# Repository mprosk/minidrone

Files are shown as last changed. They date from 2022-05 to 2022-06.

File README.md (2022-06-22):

# Minidrone

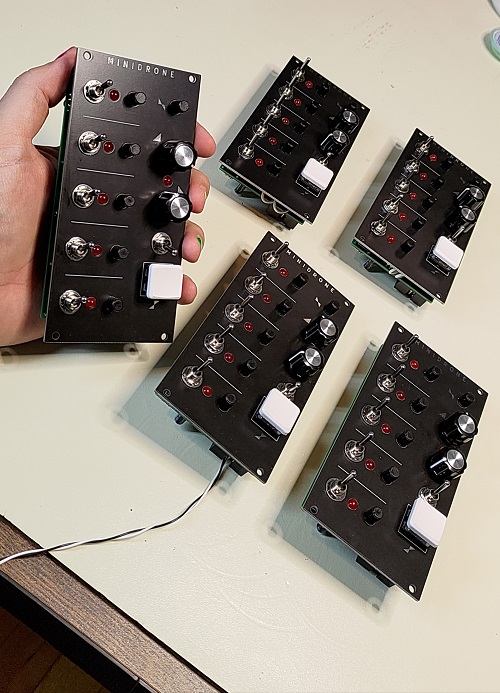
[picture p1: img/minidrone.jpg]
Minidrone


Minidrone is a drone module with a built in Attack/Release amp envelope. It contains five sawtooth oscillators each with individual pitch control and an enable switch. A master pitch control can adjust the tuning of all voices at once. 

Loosely inspired on the Elta Music Solar50

## Case

- 1/2" x 3.5" sheet
  - 2 @ 6.25"
  - 2 @ 13.8"
- 1/4" x 2.5" sheet
  - 2 @ 13.8"
- 1/2" ply
  - 1 @ 13.8" x 5.25"

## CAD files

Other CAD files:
case/minidrone_case.skp

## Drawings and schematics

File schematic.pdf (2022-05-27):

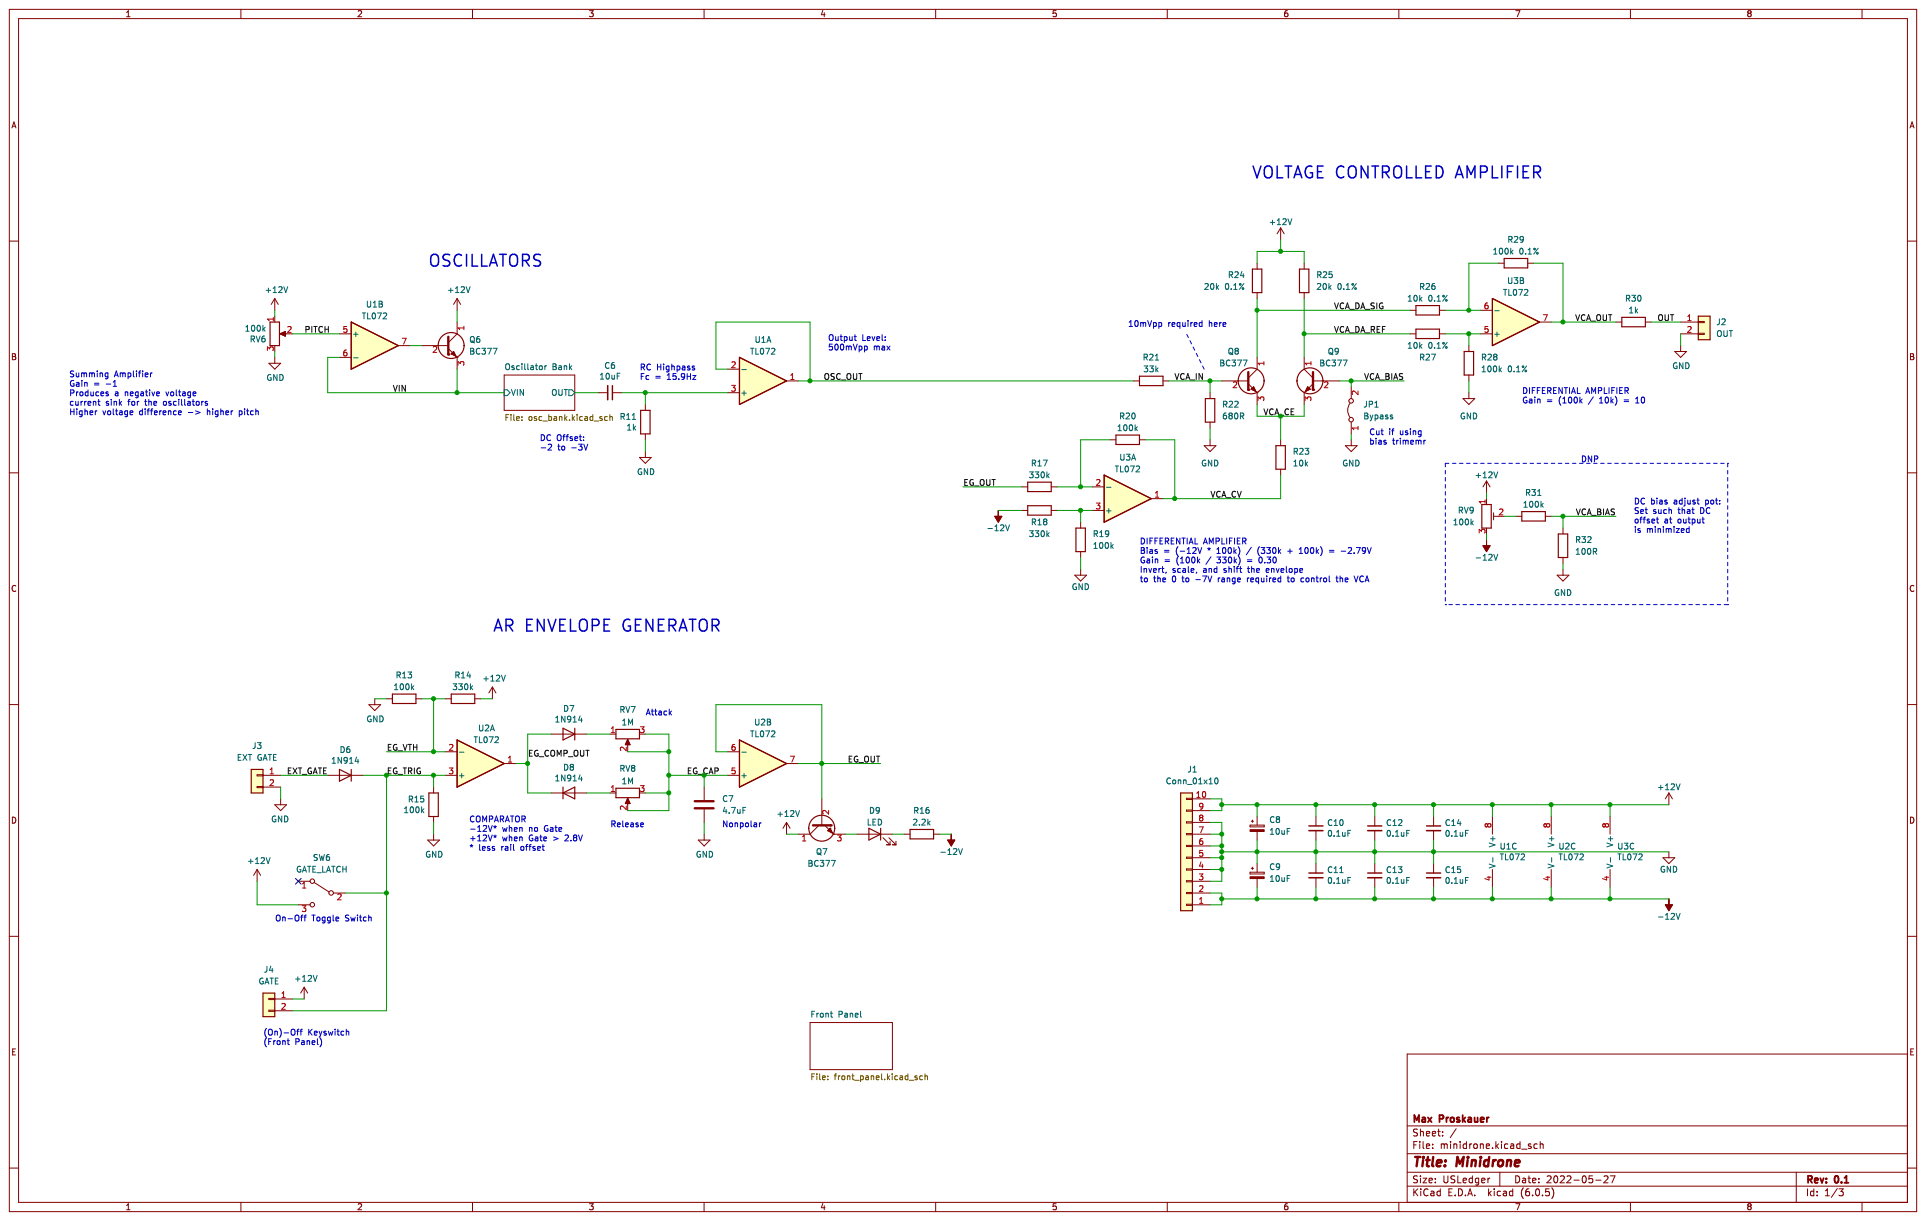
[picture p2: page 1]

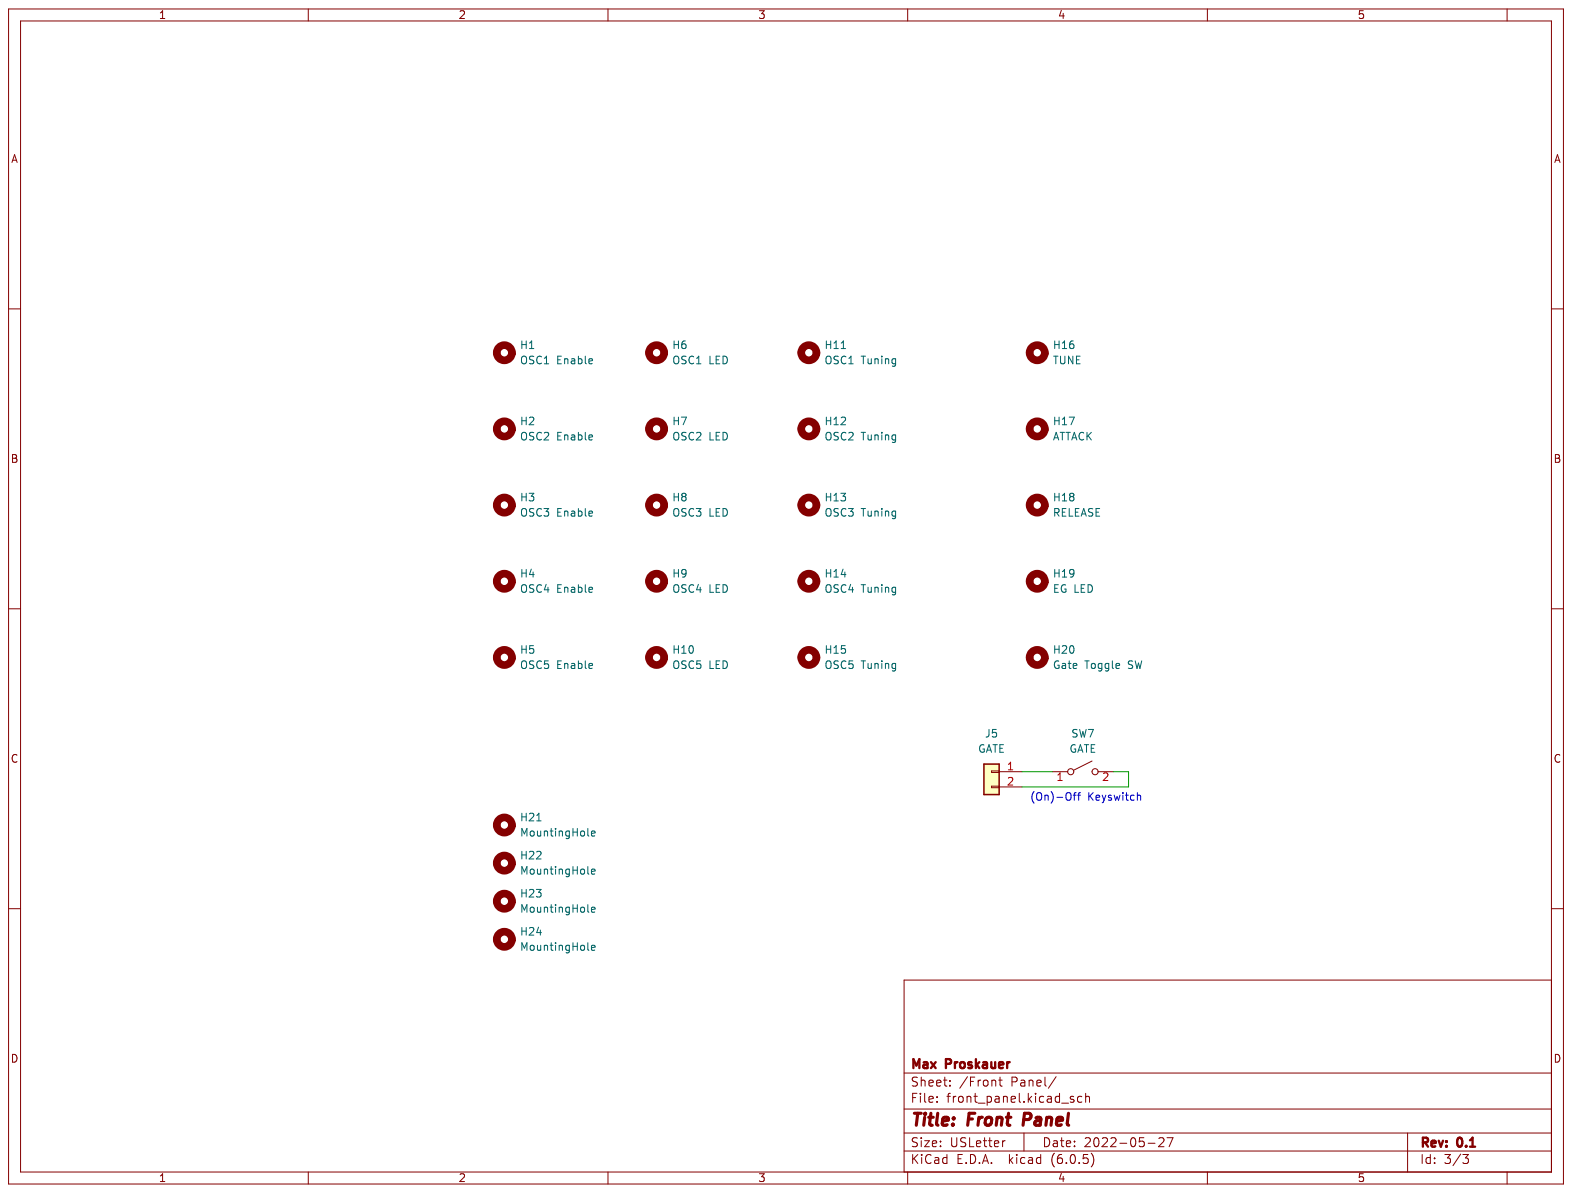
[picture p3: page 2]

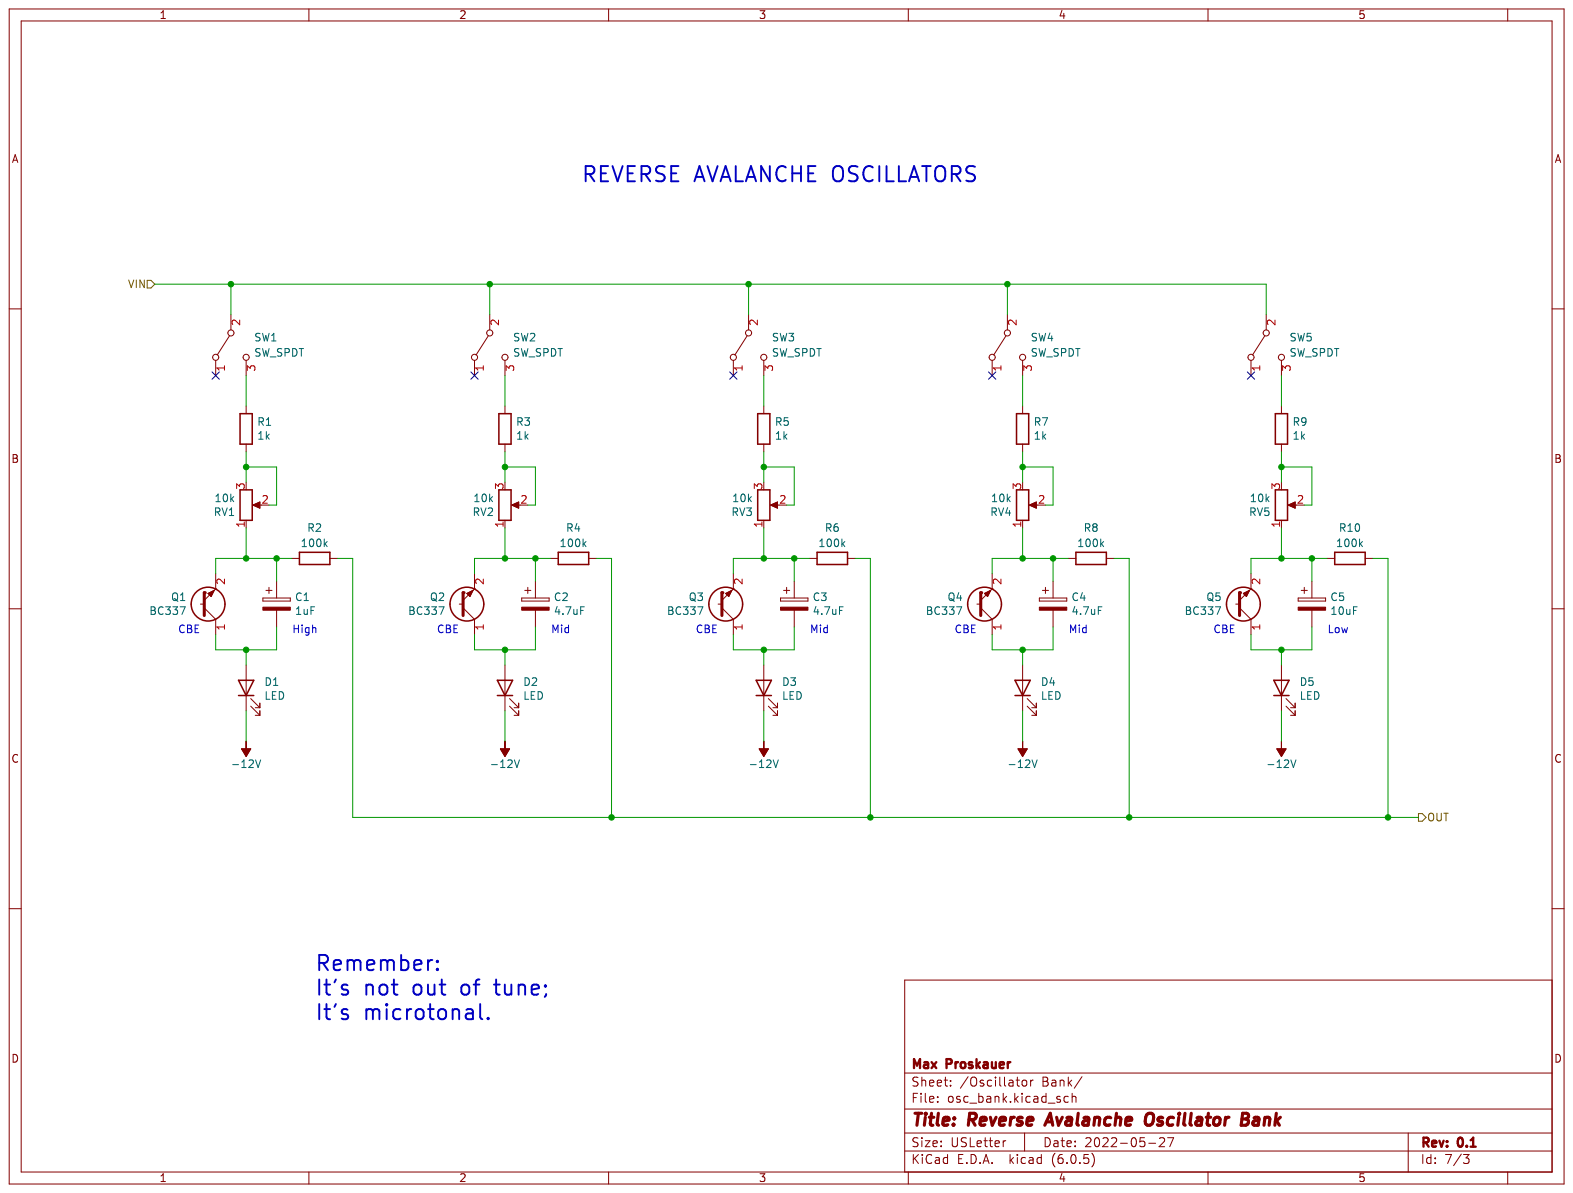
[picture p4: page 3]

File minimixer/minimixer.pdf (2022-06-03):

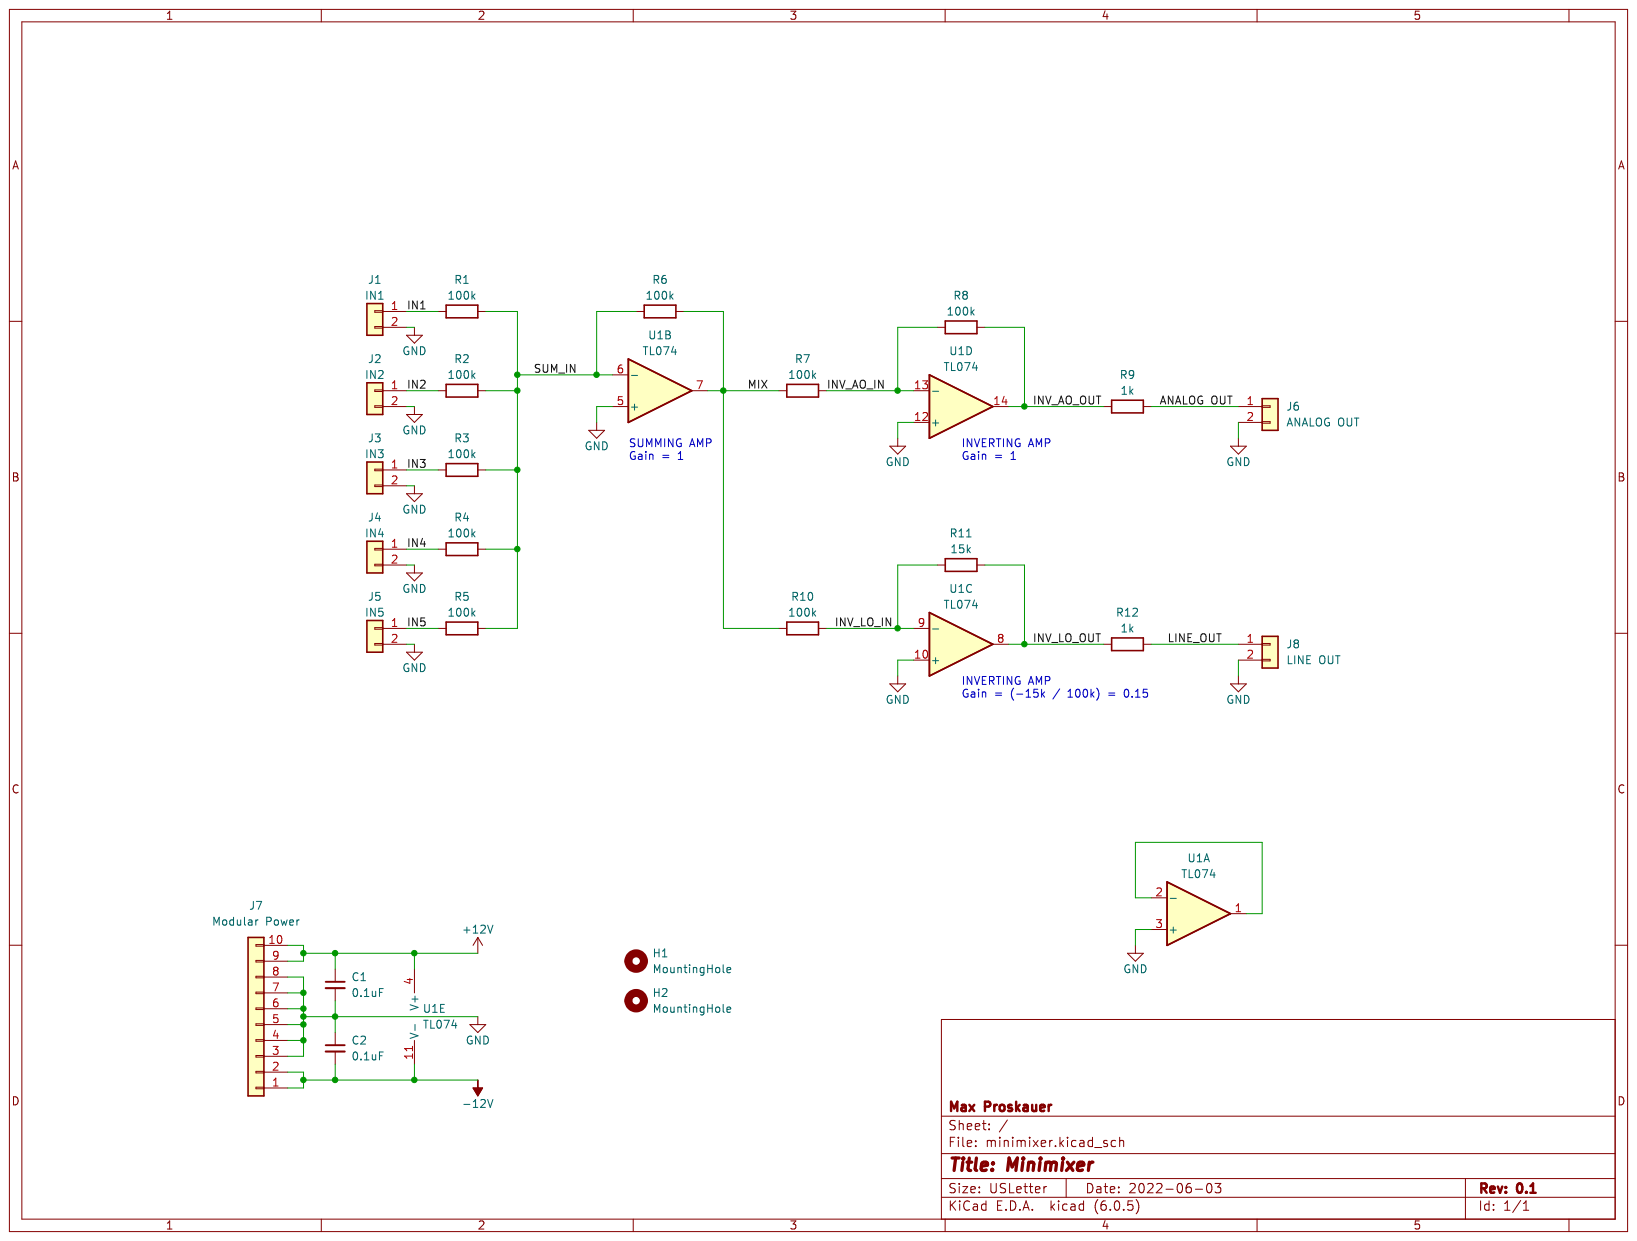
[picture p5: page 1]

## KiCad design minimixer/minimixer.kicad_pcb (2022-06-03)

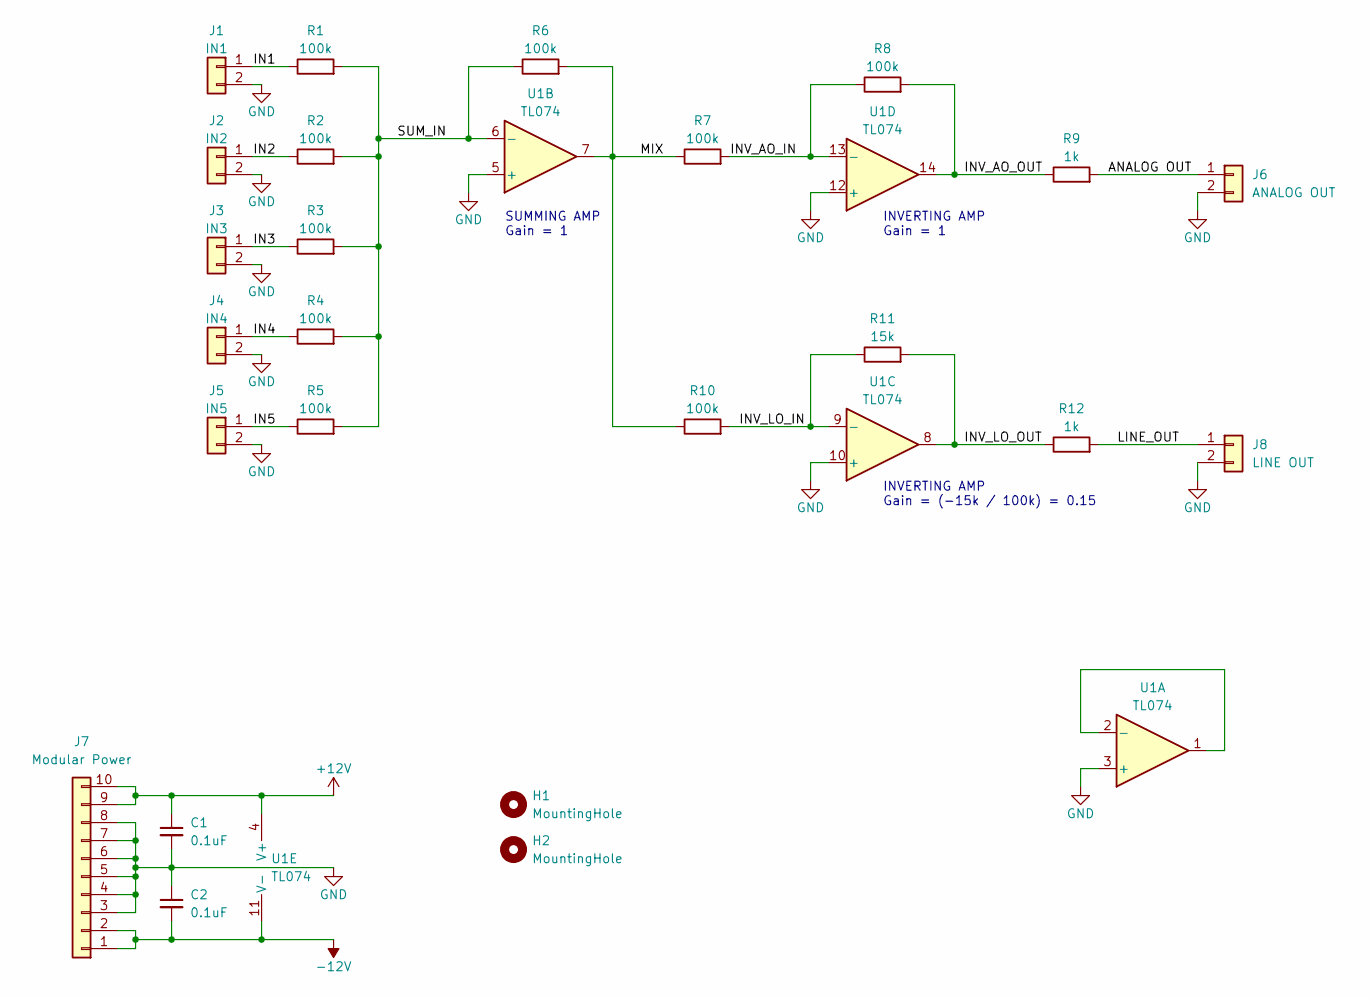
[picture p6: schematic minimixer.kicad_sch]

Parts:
C1, C2: 0.1uF; C_Disc_D3.0mm_W1.6mm_P2.50mm
H1, H2: MountingHole; MountingHole_3.2mm_M3
J1: IN1; Molex_KK-254_AE-6410-02A_1x02_P2.54mm_Vertical
J2: IN2; Molex_KK-254_AE-6410-02A_1x02_P2.54mm_Vertical
J3: IN3; Molex_KK-254_AE-6410-02A_1x02_P2.54mm_Vertical
J4: IN4; Molex_KK-254_AE-6410-02A_1x02_P2.54mm_Vertical
J5: IN5; Molex_KK-254_AE-6410-02A_1x02_P2.54mm_Vertical
J6: ANALOG OUT; Molex_KK-254_AE-6410-02A_1x02_P2.54mm_Vertical
J7: Modular Power; IDC-Header_2x05_P2.54mm_Vertical
J8: LINE OUT; Molex_KK-254_AE-6410-02A_1x02_P2.54mm_Vertical
R1, R2, R3, R4, R5, R6, R7, R10: 100k; R_Axial_DIN0207_L6.3mm_D2.5mm_P10.16mm_Horizontal
R8: 100k; R_Axial_DIN0207_L6.3mm_D2.5mm_P2.54mm_Vertical
R9, R12: 1k; R_Axial_DIN0207_L6.3mm_D2.5mm_P2.54mm_Vertical
R11: 15k; R_Axial_DIN0207_L6.3mm_D2.5mm_P2.54mm_Vertical
U1: TL074; DIP-14_W10.16mm

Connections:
+12V: C1.1, J7.9, J7.10, U1.4 (V+)
-12V: C2.2, J7.1, J7.2, U1.11 (V-)
/ANALOG OUT: J6.1, R9.2
/IN1: J1.1, R1.1
/IN2: J2.1, R2.1
/IN3: J3.1, R3.1
/IN4: J4.1, R4.1
/IN5: J5.1, R5.1
/INV_AO_IN: R7.2, R8.1, U1.13 (-)
/INV_AO_OUT: R8.2, R9.1, U1.14
/INV_LO_IN: R10.2, R11.1, U1.9 (-)
/INV_LO_OUT: R11.2, R12.1, U1.8
/LINE_OUT: J8.1, R12.2
/MIX: R6.2, R7.1, R10.1, U1.7
/SUM_IN: R1.2, R2.2, R3.2, R4.2, R5.2, R6.1, U1.6 (-)
GND: C1.2, C2.1, J1.2, J2.2, J3.2, J4.2, J5.2, J6.2, J7.3, J7.4, J7.5, J7.6, J7.7, J7.8, J8.2, U1.3 (+), U1.5 (+), U1.10 (+), U1.12 (+)
unnamed: U1.1, U1.2 (-)

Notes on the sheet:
INVERTING AMP Gain = (-15k / 100k) = 0.15
SUMMING AMP Gain = 1
INVERTING AMP Gain = 1

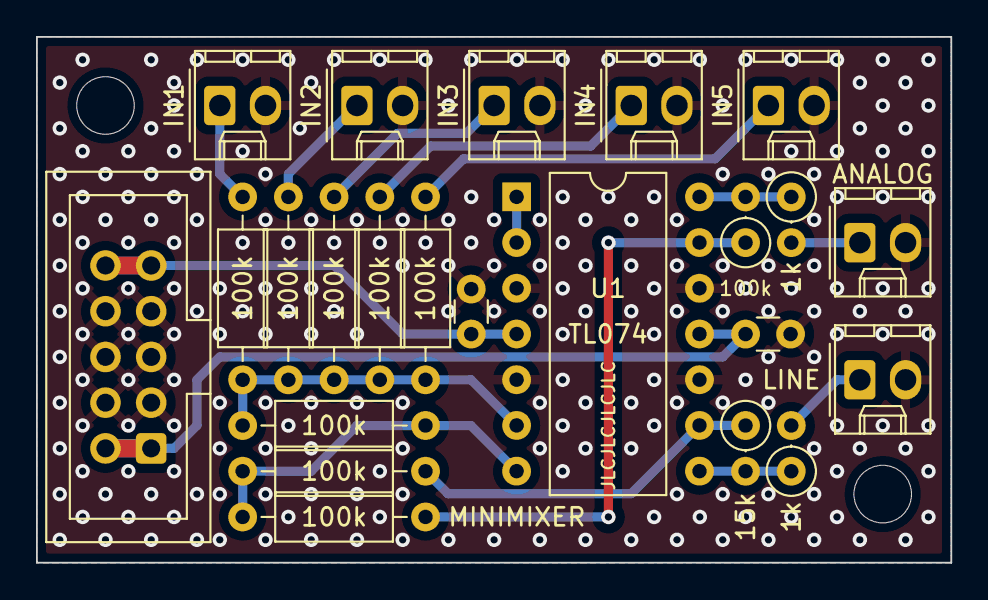
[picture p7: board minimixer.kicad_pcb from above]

Board: 2 copper layers, 50.8 x 29.2 mm, 25 parts (0 on the bottom side), 17 nets.

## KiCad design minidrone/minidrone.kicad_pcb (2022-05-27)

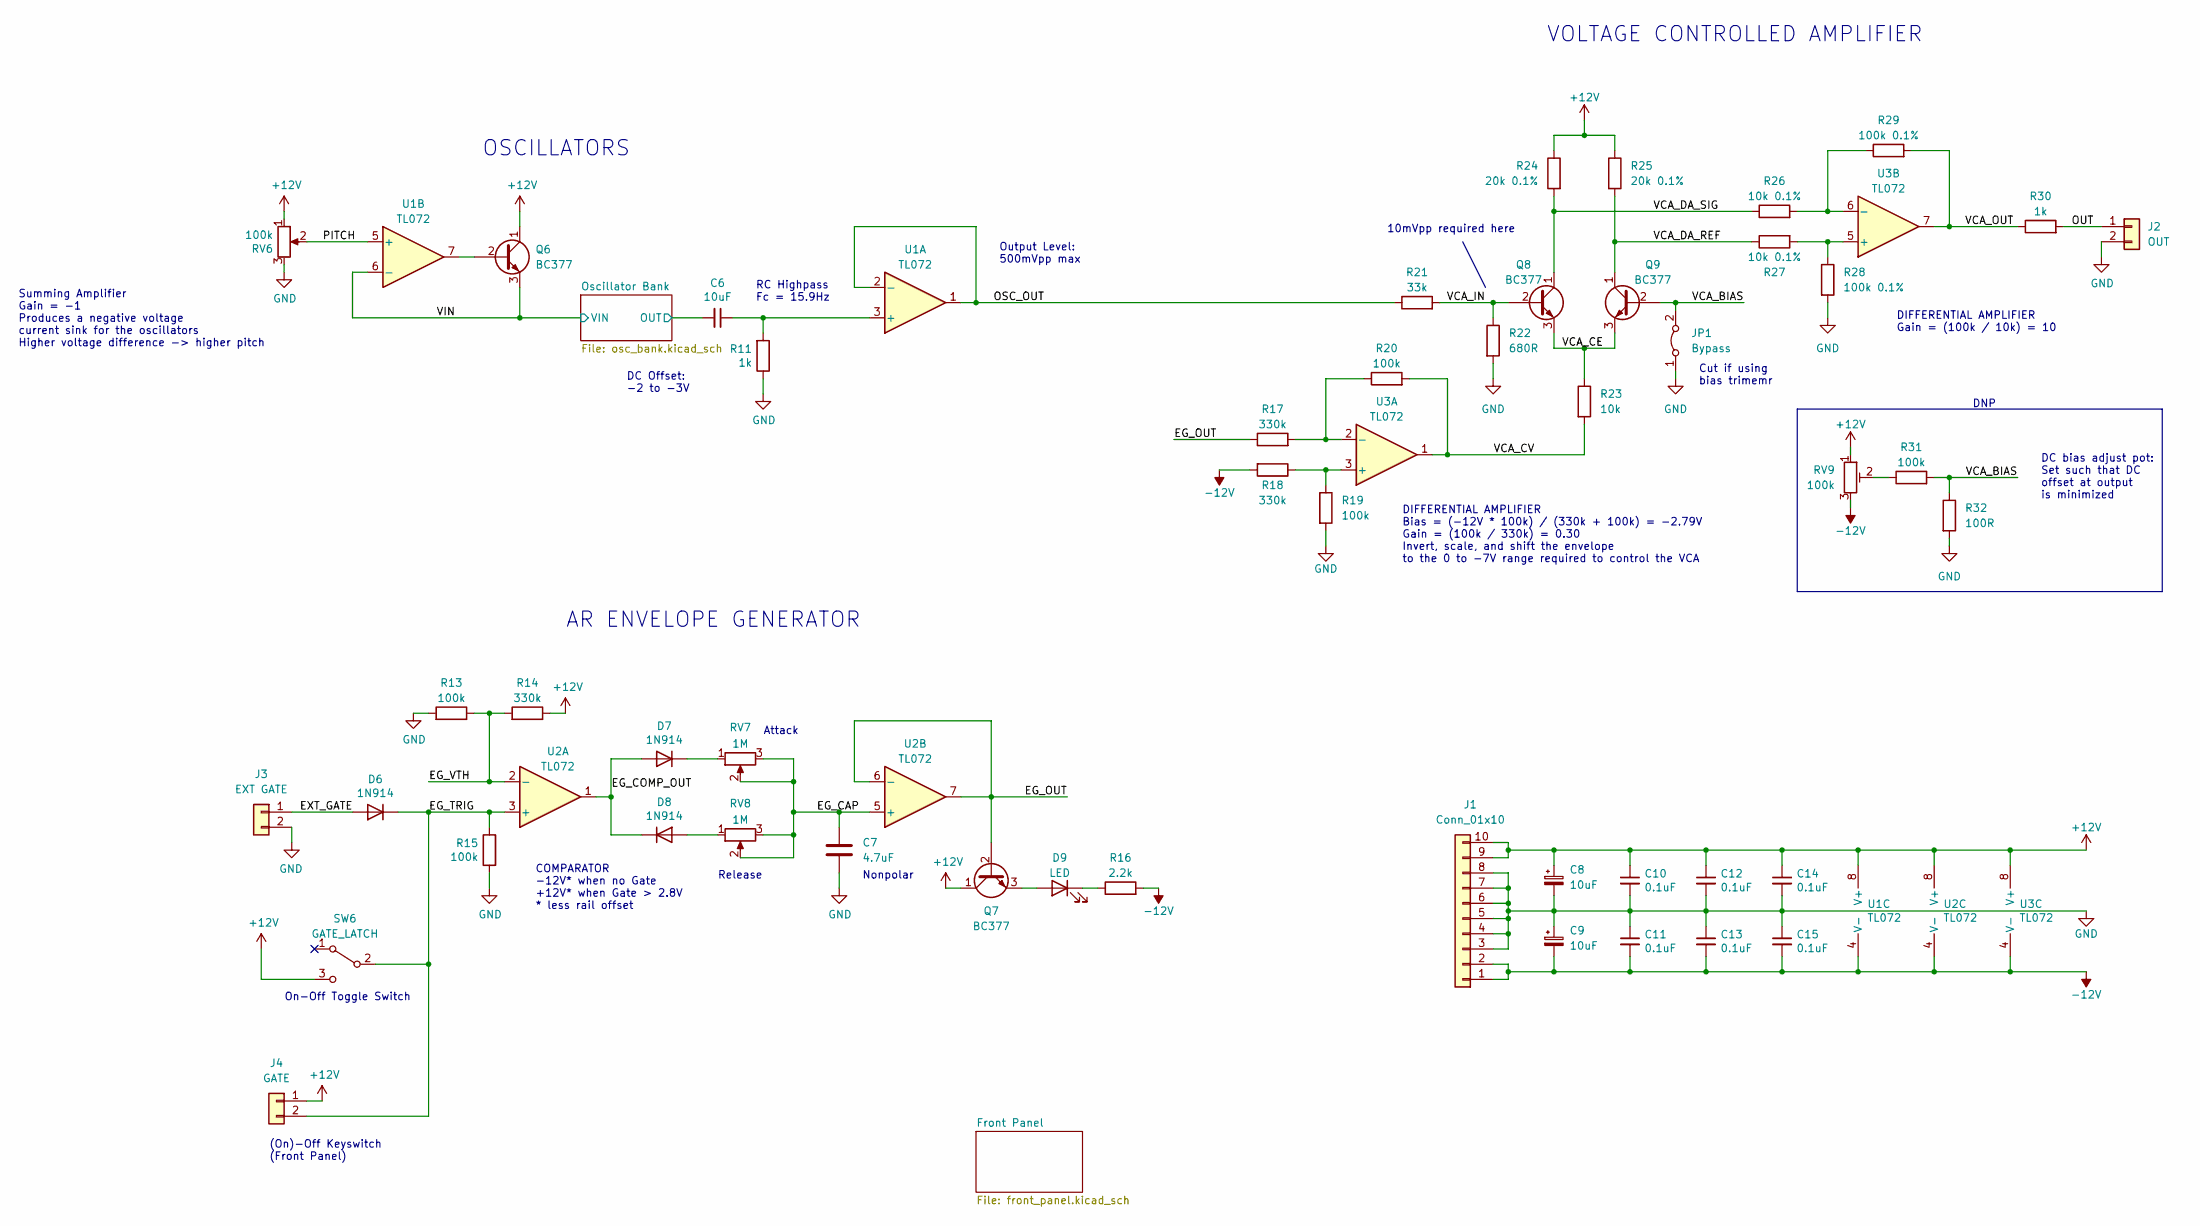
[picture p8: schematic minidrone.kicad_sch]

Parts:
C6: 10uF; C_Disc_D3.0mm_W1.6mm_P2.50mm
C7: 4.7uF; C_Disc_D3.0mm_W1.6mm_P2.50mm
C8, C9: 10uF; CP_Radial_D5.0mm_P2.50mm
C10, C11, C12, C13, C14, C15: 0.1uF; C_Disc_D3.0mm_W1.6mm_P2.50mm
D6, D7, D8: 1N914; D_DO-35_SOD27_P7.62mm_Horizontal
D9: LED; LED_D5.0mm
J1: Conn_01x10; IDC-Header_2x05_P2.54mm_Vertical
J2: OUT; Molex_KK-254_AE-6410-02A_1x02_P2.54mm_Vertical
J3: EXT GATE; Molex_KK-254_AE-6410-02A_1x02_P2.54mm_Vertical
J4: GATE; Molex_KK-254_AE-6410-02A_1x02_P2.54mm_Vertical
JP1: Bypass; SolderJumper-2_P1.3mm_Bridged_RoundedPad1.0x1.5mm
Q6, Q7, Q8, Q9: BC377; TO-92L_Inline_Wide
R11, R30: 1k; R_Axial_DIN0207_L6.3mm_D2.5mm_P10.16mm_Horizontal
R13, R15, R19, R20: 100k; R_Axial_DIN0207_L6.3mm_D2.5mm_P10.16mm_Horizontal
R14, R17, R18: 330k; R_Axial_DIN0207_L6.3mm_D2.5mm_P10.16mm_Horizontal
R16: 2.2k; R_Axial_DIN0207_L6.3mm_D2.5mm_P10.16mm_Horizontal
R21: 33k; R_Axial_DIN0207_L6.3mm_D2.5mm_P10.16mm_Horizontal
R22: 680R; R_Axial_DIN0207_L6.3mm_D2.5mm_P10.16mm_Horizontal
R23: 10k; R_Axial_DIN0207_L6.3mm_D2.5mm_P10.16mm_Horizontal
R24, R25: 20k 0.1%; R_Axial_DIN0207_L6.3mm_D2.5mm_P10.16mm_Horizontal
R26, R27: 10k 0.1%; R_Axial_DIN0207_L6.3mm_D2.5mm_P10.16mm_Horizontal
R28, R29: 100k 0.1%; R_Axial_DIN0207_L6.3mm_D2.5mm_P10.16mm_Horizontal
R31: 100k; R_Axial_DIN0207_L6.3mm_D2.5mm_P2.54mm_Vertical
R32: 100R; R_Axial_DIN0207_L6.3mm_D2.5mm_P2.54mm_Vertical
RV6: 100k; Bourns_PVT09A
RV7, RV8: 1M; Bourns_PDB12-H
RV9: 100k; Potentiometer_Bourns_3296Y_Vertical
SW6: GATE_LATCH; Switch_SPDT
U1, U2, U3: TL072; DIP-8_W7.62mm

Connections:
+12V: C8.1, C10.1, C12.1, C14.1, J1.9, J1.10, J4.1, Q6.1 (C), Q7.1 (C), R14.1, R24.1, R25.1, RV6.1, RV9.1, SW6.3 (C), U1.8 (V+), U2.8 (V+), U3.8 (V+)
-12V: C9.2, C11.2, C13.2, C15.2, J1.1, J1.2, R16.2, R18.2, RV9.3, U1.4 (V-), U2.4 (V-), U3.4 (V-); also elsewhere on the board
/EG_CAP: C7.1, RV7.2, RV7.3, RV8.2, RV8.3, U2.5 (+)
/EG_COMP_OUT: D7.2 (A), D8.1 (K), U2.1
/EG_OUT: Q7.2 (B), R17.1, U2.6 (-), U2.7
/EG_TRIG: D6.1 (K), J4.2, R15.1, SW6.2 (B), U2.3 (+)
/EG_VTH: R13.1, R14.2, U2.2 (-)
/EXT_GATE: D6.2 (A), J3.1
/OSC_OUT: R21.1, U1.1, U1.2 (-)
/OUT: J2.1, R30.2
/Oscillator Bank/OUT: C6.2; also elsewhere on the board
/PITCH: RV6.2, U1.5 (+)
/VCA_BIAS: JP1.2 (B), Q9.2 (B), R31.2, R32.1
/VCA_CE: Q8.3 (E), Q9.3 (E), R23.1
/VCA_CV: R20.2, R23.2, U3.1
/VCA_DA_REF: Q9.1 (C), R25.2, R27.1
/VCA_DA_SIG: Q8.1 (C), R24.2, R26.1
/VCA_IN: Q8.2 (B), R21.2, R22.1
/VCA_OUT: R29.2, R30.1, U3.7
/VIN: Q6.3 (E), U1.6 (-); also elsewhere on the board
GND: C7.2, C8.2, C9.1, C10.2, C11.1, C12.2, C13.1, C14.2, C15.1, J1.3, J1.4, J1.5, J1.6, J1.7, J1.8, J2.2, J3.2, JP1.1 (A), R11.1, R13.2, R15.2, R19.2, R22.2, R28.2, R32.2, RV6.3
unnamed: C6.1, R11.2, U1.3 (+)
unnamed: D7.1 (K), RV7.1
unnamed: D8.2 (A), RV8.1
unnamed: D9.1 (K), R16.1
unnamed: D9.2 (A), Q7.3 (E)
unnamed: Q6.2 (B), U1.7
unnamed: R17.2, R20.1, U3.2 (-)
unnamed: R18.1, R19.1, U3.3 (+)
unnamed: R26.2, R29.1, U3.6 (-)
unnamed: R27.2, R28.1, U3.5 (+)
unnamed: R31.1, RV9.2

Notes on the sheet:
On-Off Toggle Switch
DC bias adjust pot: Set such that DC offset at output is minimized
COMPARATOR -12V* when no Gate +12V* when Gate > 2.8V * less rail offset
Release
AR ENVELOPE GENERATOR
OSCILLATORS
VOLTAGE CONTROLLED AMPLIFIER
DIFFERENTIAL AMPLIFIER Bias = (-12V * 100k) / (330k + 100k) = -2.79V Gain = (100k / 330k) = 0.30 Invert, scale, and shift the envelope to the 0 to -7V range required to control the VCA
DIFFERENTIAL AMPLIFIER Gain = (100k / 10k) = 10
DNP
Summing Amplifier Gain = -1 Produces a negative voltage current sink for the oscillators Higher voltage difference -> higher pitch
RC Highpass Fc = 15.9Hz
DC Offset: -2 to -3V
Attack
Output Level: 500mVpp max
10mVpp required here
Nonpolar
Cut if using bias trimemr
(On)-Off Keyswitch (Front Panel)

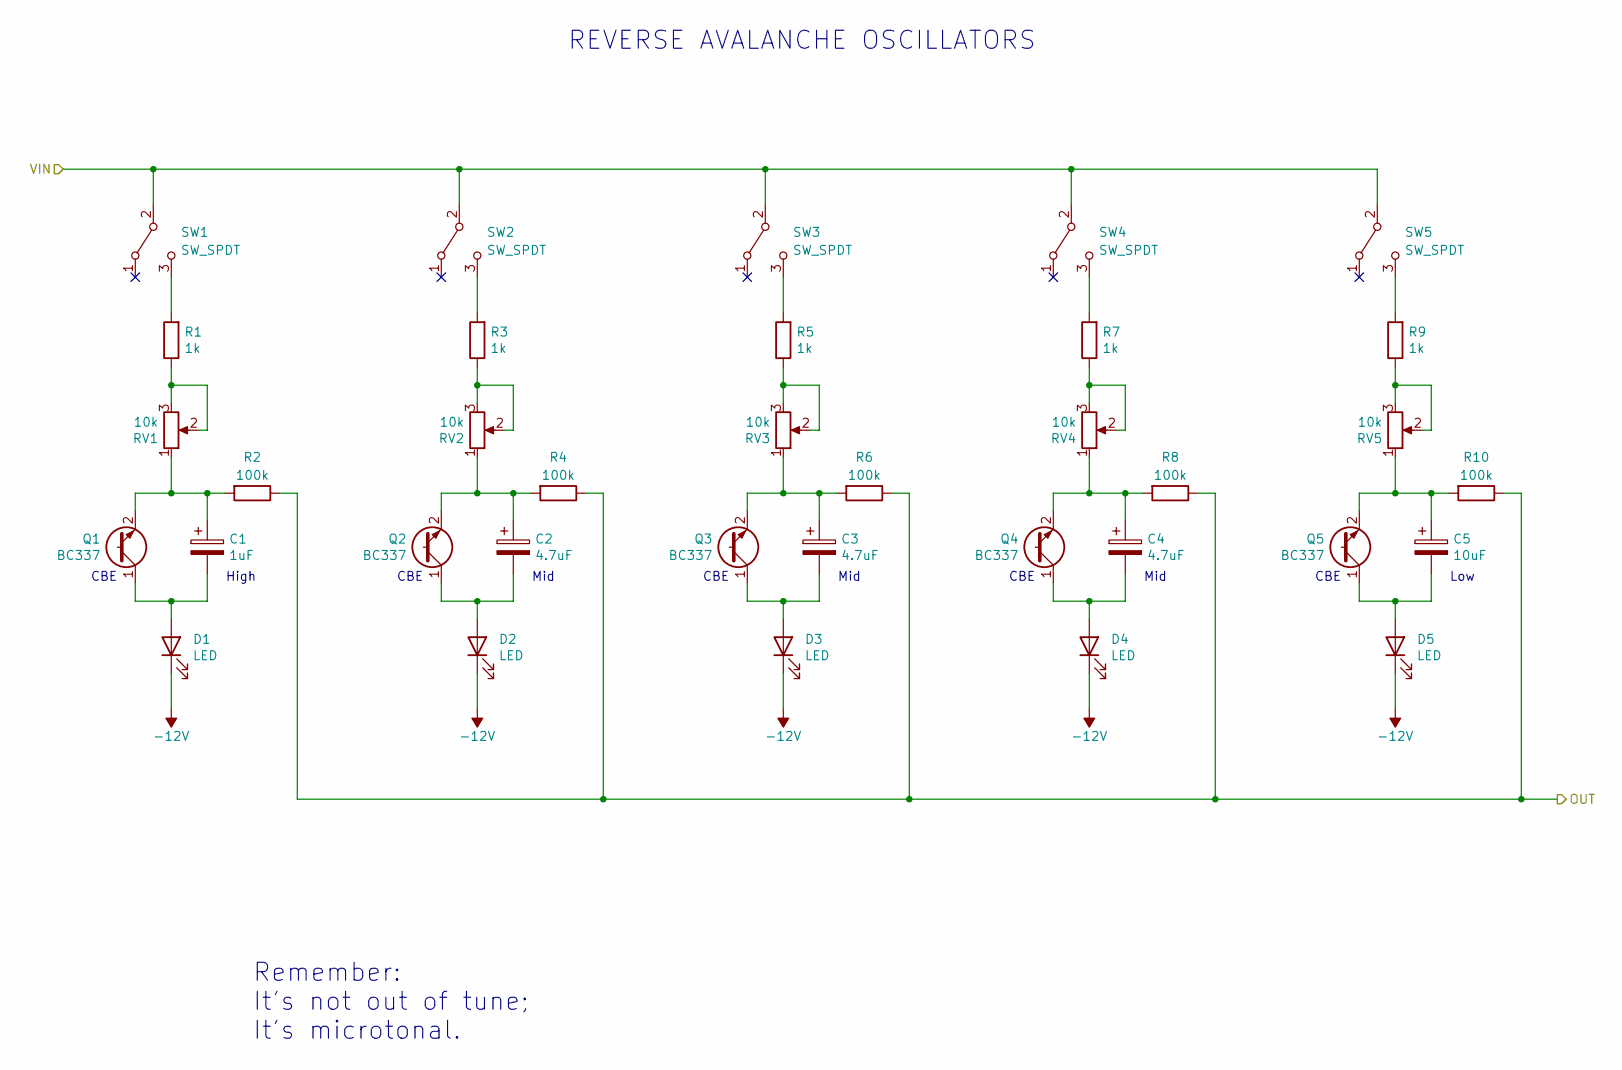
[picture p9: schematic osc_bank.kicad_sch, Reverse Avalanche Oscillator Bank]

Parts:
C1: 1uF; CP_Radial_D5.0mm_P2.50mm
C2, C3, C4: 4.7uF; CP_Radial_D5.0mm_P2.50mm
C5: 10uF; CP_Radial_D5.0mm_P2.50mm
D1, D2, D3, D4, D5: LED; LED_D5.0mm
Q1, Q2, Q3, Q4, Q5: BC337; TO-92-2
R1, R3, R5, R7, R9: 1k; R_Axial_DIN0207_L6.3mm_D2.5mm_P10.16mm_Horizontal
R2, R4, R6, R8, R10: 100k; R_Axial_DIN0207_L6.3mm_D2.5mm_P10.16mm_Horizontal
RV1, RV2, RV3, RV4, RV5: 10k; Bourns_PVT09A
SW1, SW2, SW3, SW4, SW5: SW_SPDT; Switch_SPDT

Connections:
-12V: D1.1 (K), D2.1 (K), D3.1 (K), D4.1 (K), D5.1 (K); also elsewhere on the board
/Oscillator Bank/OUT: R2.1, R4.1, R6.1, R8.1, R10.1; also elsewhere on the board
/VIN: SW1.2 (B), SW2.2 (B), SW3.2 (B), SW4.2 (B), SW5.2 (B); also elsewhere on the board
unnamed: C1.1, Q1.2 (E), R2.2, RV1.1
unnamed: C1.2, D1.2 (A), Q1.1 (C)
unnamed: C2.1, Q2.2 (E), R4.2, RV2.1
unnamed: C2.2, D2.2 (A), Q2.1 (C)
unnamed: C3.1, Q3.2 (E), R6.2, RV3.1
unnamed: C3.2, D3.2 (A), Q3.1 (C)
unnamed: C4.1, Q4.2 (E), R8.2, RV4.1
unnamed: C4.2, D4.2 (A), Q4.1 (C)
unnamed: C5.1, Q5.2 (E), R10.2, RV5.1
unnamed: C5.2, D5.2 (A), Q5.1 (C)
unnamed: R1.1, RV1.2, RV1.3
unnamed: R1.2, SW1.3 (C)
unnamed: R3.1, RV2.2, RV2.3
unnamed: R3.2, SW2.3 (C)
unnamed: R5.1, RV3.2, RV3.3
unnamed: R5.2, SW3.3 (C)
unnamed: R7.1, RV4.2, RV4.3
unnamed: R7.2, SW4.3 (C)
unnamed: R9.1, RV5.2, RV5.3
unnamed: R9.2, SW5.3 (C)

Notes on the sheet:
Mid
CBE
High
Remember: It's not out of tune; It's microtonal.
Low
REVERSE AVALANCHE OSCILLATORS

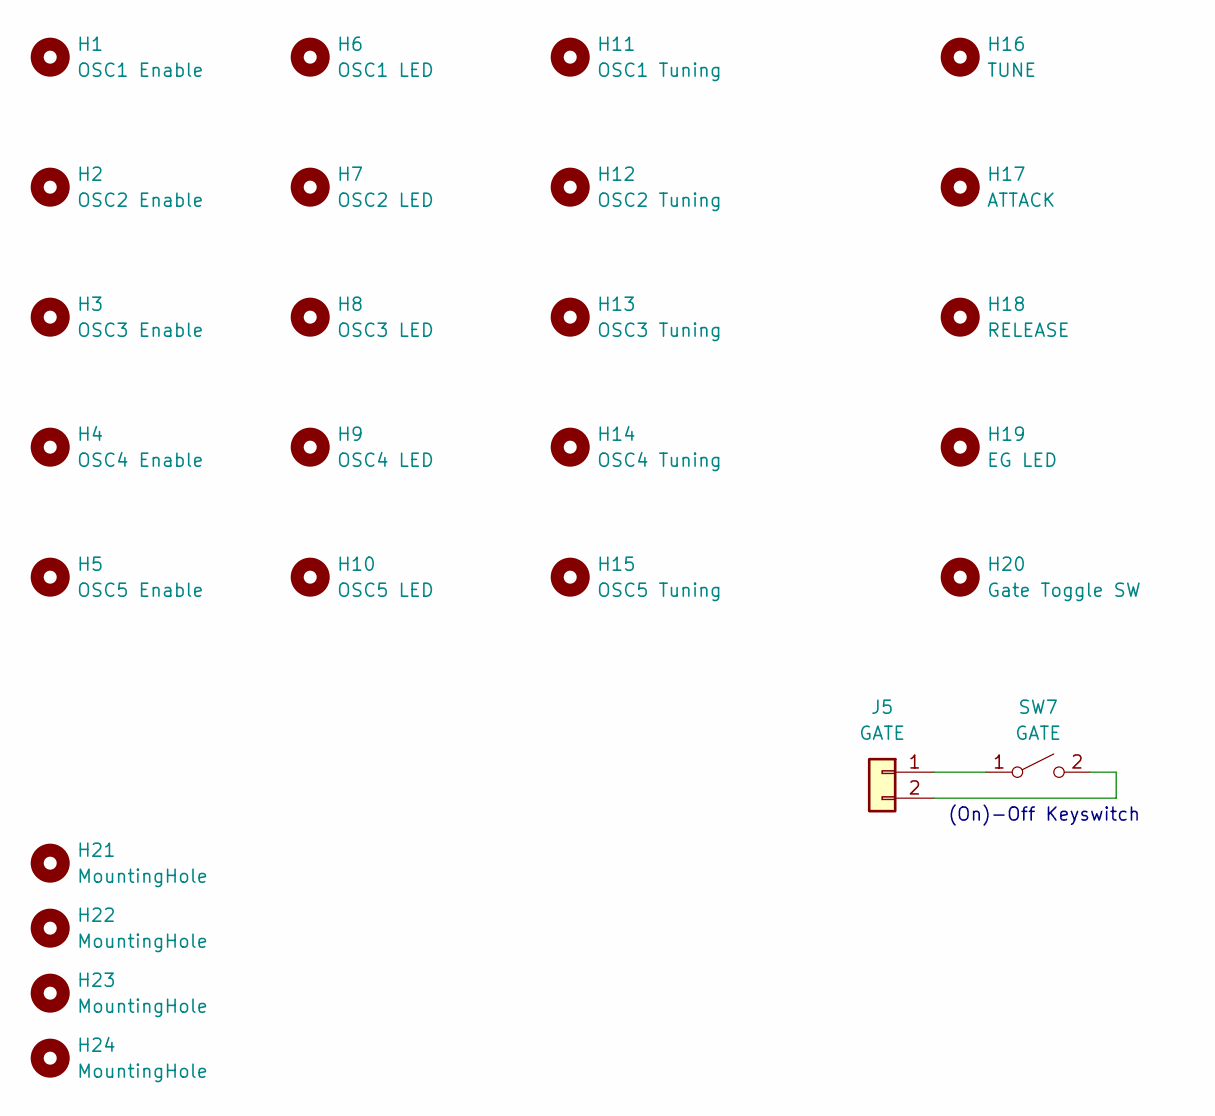
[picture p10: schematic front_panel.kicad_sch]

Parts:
H1: OSC1 Enable; Hole_Toggle_Switch
H2: OSC2 Enable; Hole_Toggle_Switch
H3: OSC3 Enable; Hole_Toggle_Switch
H4: OSC4 Enable; Hole_Toggle_Switch
H5: OSC5 Enable; Hole_Toggle_Switch
H6: OSC1 LED; Hole_LED_5mm
H7: OSC2 LED; Hole_LED_5mm
H8: OSC3 LED; Hole_LED_5mm
H9: OSC4 LED; Hole_LED_5mm
H10: OSC5 LED; Hole_LED_5mm
H11: OSC1 Tuning; Hole_Pot
H12: OSC2 Tuning; Hole_Pot
H13: OSC3 Tuning; Hole_Pot
H14: OSC4 Tuning; Hole_Pot
H15: OSC5 Tuning; Hole_Pot
H16: TUNE; Hole_Pot
H17: ATTACK; Hole_Pot
H18: RELEASE; Hole_Pot
H19: EG LED; Hole_LED_5mm
H20: Gate Toggle SW; Hole_Toggle_Switch
H21, H22, H23, H24: MountingHole; MountingHole_3.2mm_M3
J5: GATE; SMD_Connector
SW7: GATE; SW_Kailh_Choc_1.00u_PCB

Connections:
unnamed: J5.1, SW7.1 (A)
unnamed: J5.2, SW7.2 (B)

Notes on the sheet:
(On)-Off Keyswitch

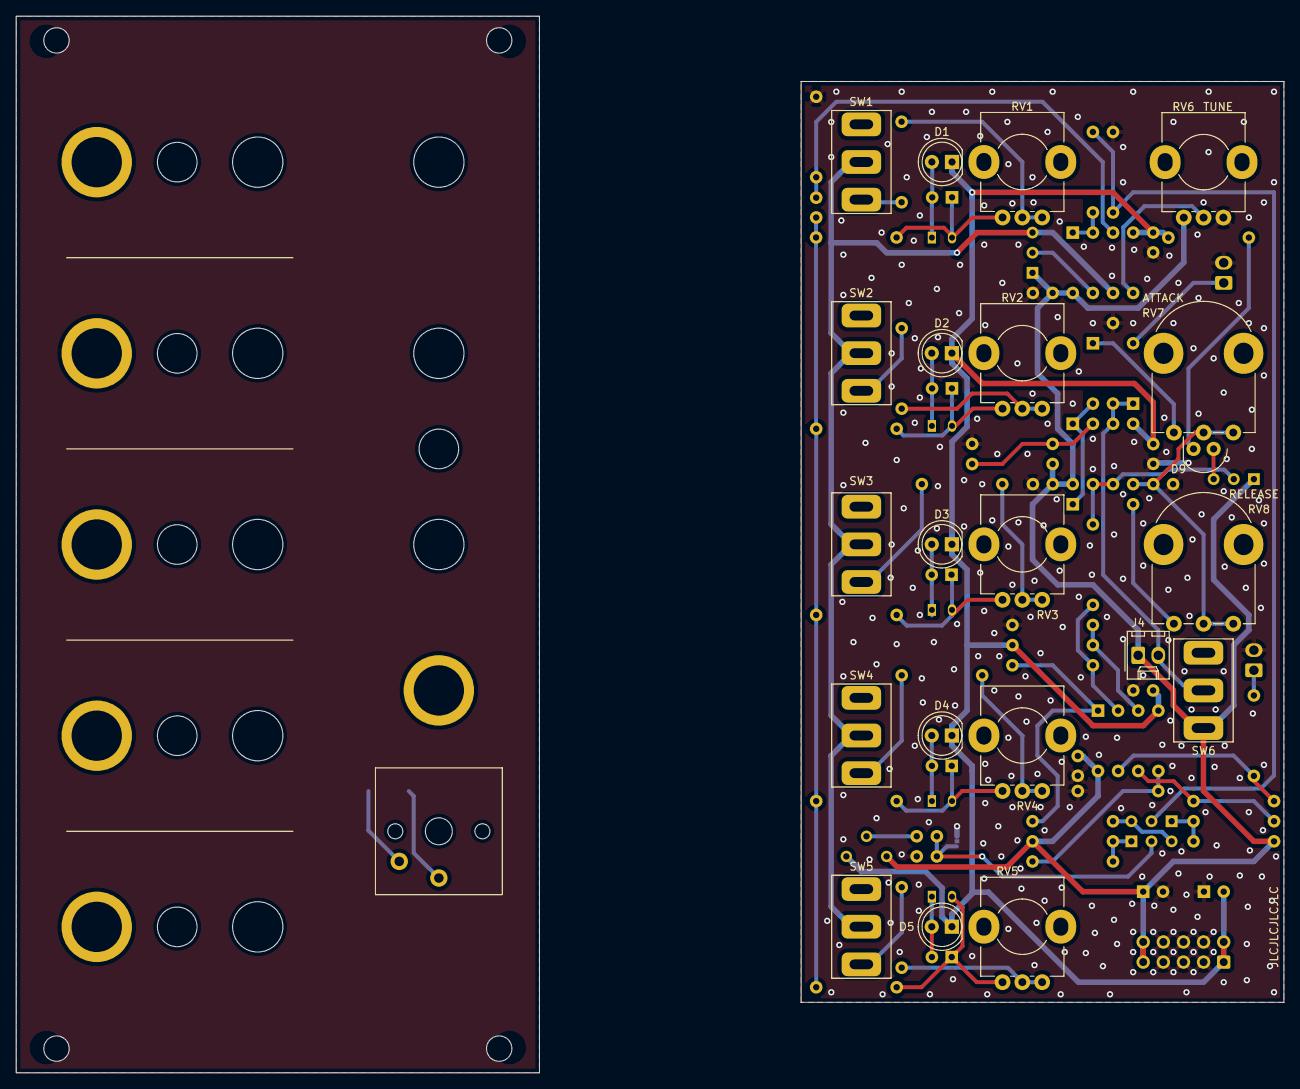
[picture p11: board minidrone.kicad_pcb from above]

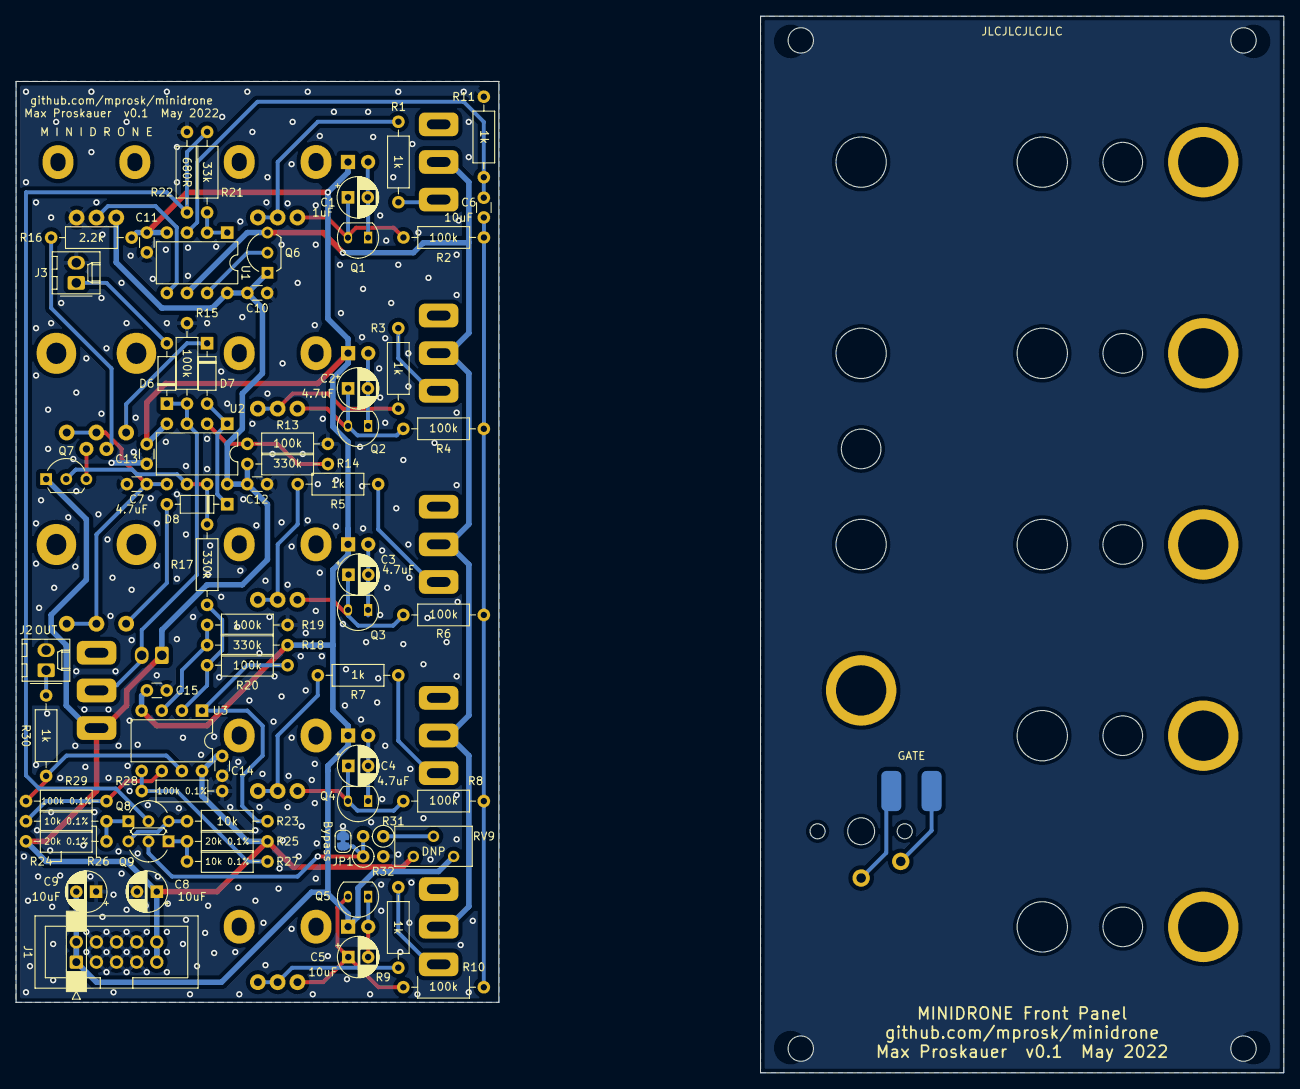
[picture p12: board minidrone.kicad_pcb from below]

Board: 2 copper layers, 60.9 x 116.2 mm, 113 parts (67 on the bottom side), 54 nets.

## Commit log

2022-05-02 Copy contents from other repo
    [minidrone.kicad_pcb, minidrone.kicad_sch, osc_bank.kicad_sch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]
2022-05-12 Correct pot footprints. continue layout
    [minidrone.kicad_pcb, minidrone.kicad_sch, osc_bank.kicad_sch]
2022-05-13 Continue layout
    [minidrone.kicad_pcb, minidrone.kicad_sch, osc_bank.kicad_sch]
2022-05-13 Add 3d model of case
    [minidrone_case.skp]
2022-05-13 Complete layout
    [minidrone.kicad_pcb, minidrone.kicad_sch]
2022-05-13 Start front panel
    [minidrone.kicad_pcb]
2022-05-17 Lay out front panel. WIP updating mainboard layout
    [front_panel.kicad_sch, minidrone.kicad_pcb, minidrone.kicad_sch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]
2022-05-23 Complete initial layout
    [front_panel.kicad_sch, minidrone.kicad_pcb, minidrone.kicad_sch]
2022-05-27 Complete cosmetics layout
    [minidrone.kicad_pcb]
2022-05-27 Export gerbers
    [minidrone-B_Cu.gbr, minidrone-B_Mask.gbr, minidrone-B_Silkscreen.gbr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]
2022-05-27 Export schematic to PDF
    [front_panel.kicad_sch, minidrone.kicad_sch, osc_bank.kicad_sch]
2022-06-01 Begin layout of minidrone aux panel
    [aux_panel.kicad_pcb, aux_panel.kicad_sch]
2022-06-03 Add minimixer board
    [minimixer-B_Cu.gbr, minimixer-B_Mask.gbr, minimixer-B_Silkscreen.gbr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]
2022-06-05 Complete aux panel PCB
    [aux_panel-B_Cu.gbr, aux_panel-B_Mask.gbr, aux_panel-B_Paste.gbr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]
2022-06-06 Finalize case design
    [minidrone_case.skp]
2022-06-17 Fix schematic issues identified in first production run. PCB fixes TODO!
    [minidrone.kicad_sch, osc_bank.kicad_sch]
2023-06-23 Add gerber files for aluminum aux panel
